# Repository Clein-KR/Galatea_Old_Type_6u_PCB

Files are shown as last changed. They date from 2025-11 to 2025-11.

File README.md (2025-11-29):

# Galatea Old Type 6u PCB

<br />

Geonworks에서 판매했던 Studio Kestra의 Galatea 구형 버전과 호환되는 a87 TKL 유니버셜 PCB입니다.

<br />

**Rendering**

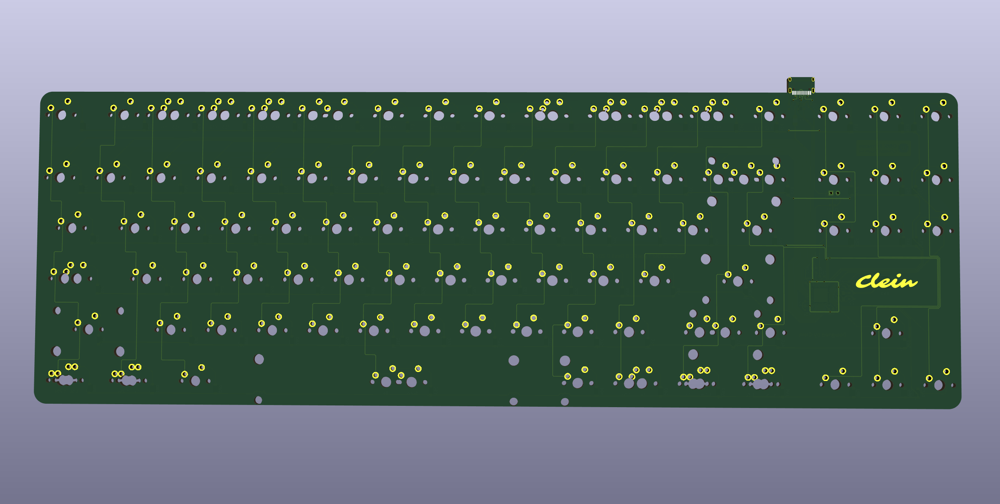
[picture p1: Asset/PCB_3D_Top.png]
PCB Rendering Top View

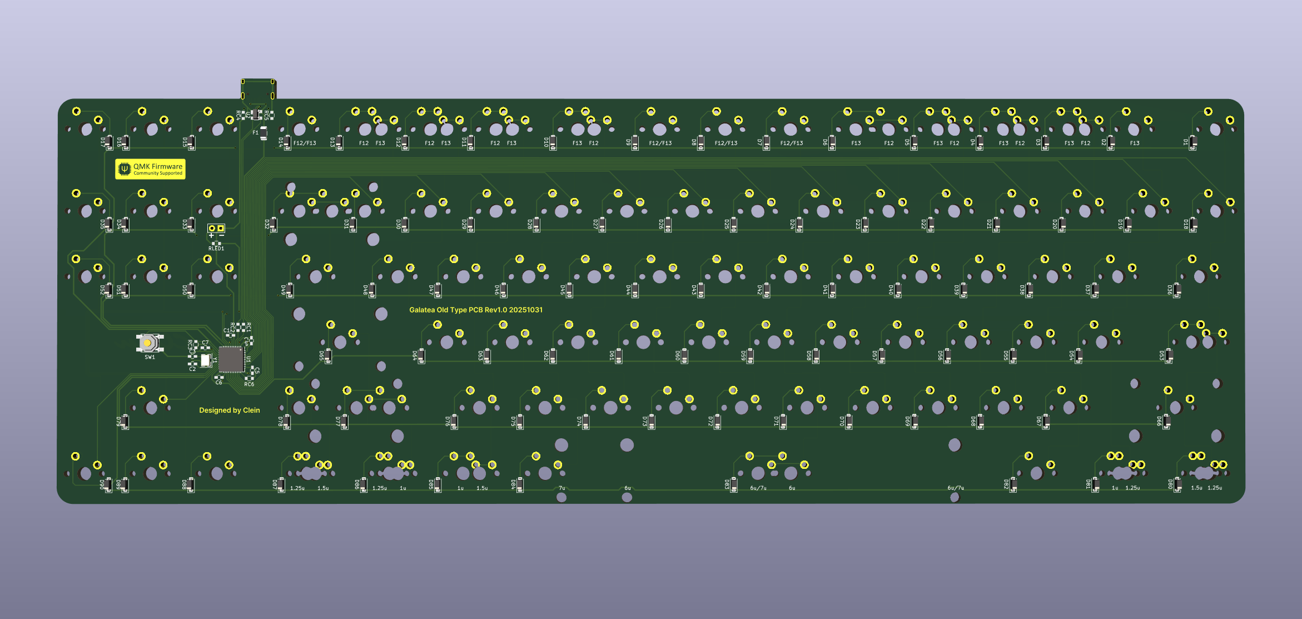
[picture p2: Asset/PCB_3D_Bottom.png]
PCB Rendering Bottom View


<br />

**Prototype**

PCB Prototype Top View
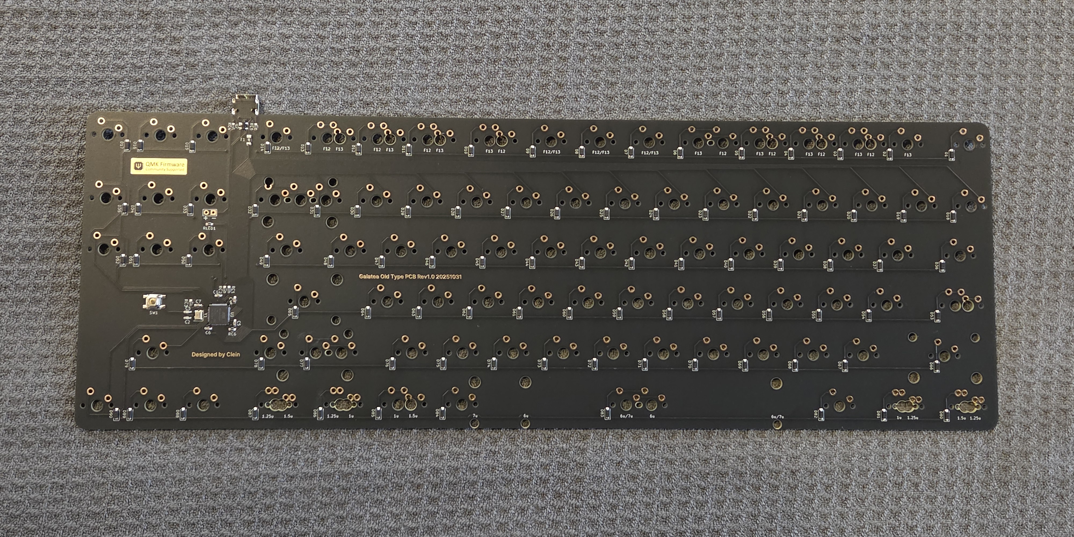
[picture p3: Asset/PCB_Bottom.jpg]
PCB Prototype Bottom View


<br />

**Detail**

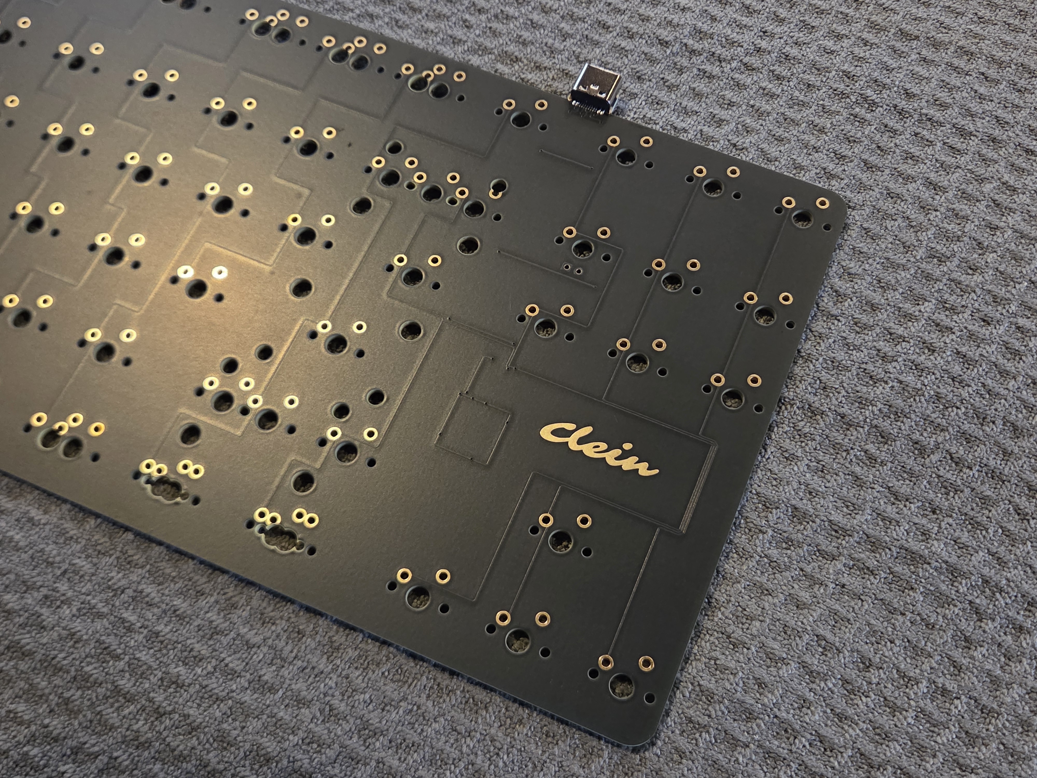
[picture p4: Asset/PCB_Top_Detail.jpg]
PCB Prototype Top Detail View

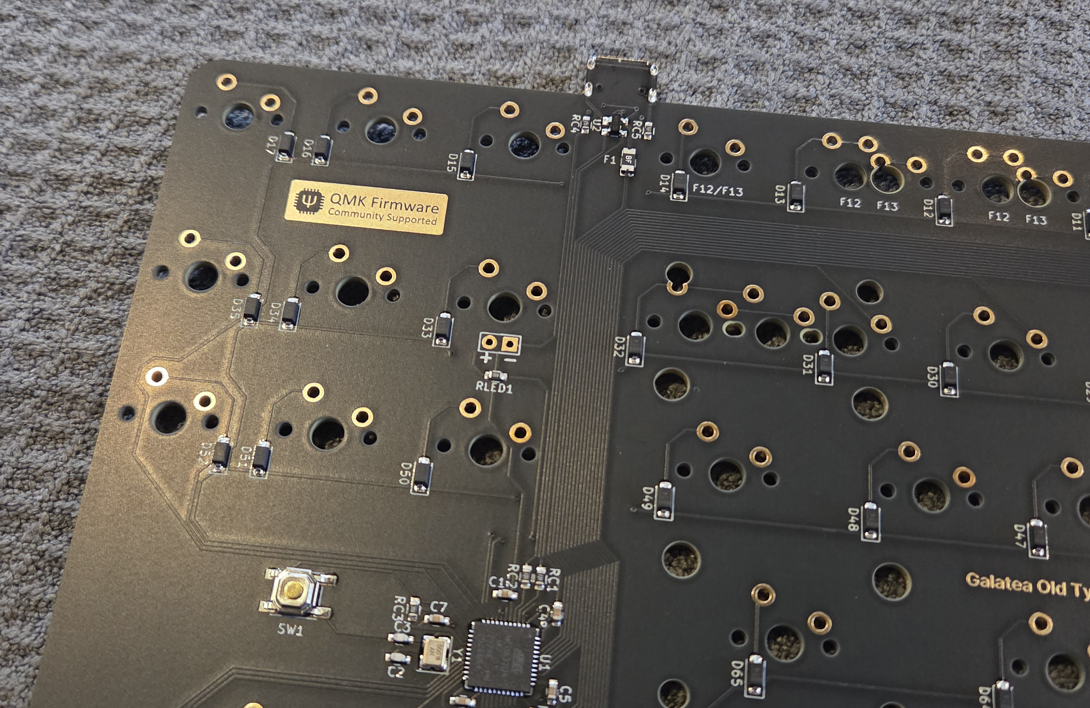
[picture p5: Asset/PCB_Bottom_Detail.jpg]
PCB Prototype Bottom Detail View


<br />

**Compatibility Test**

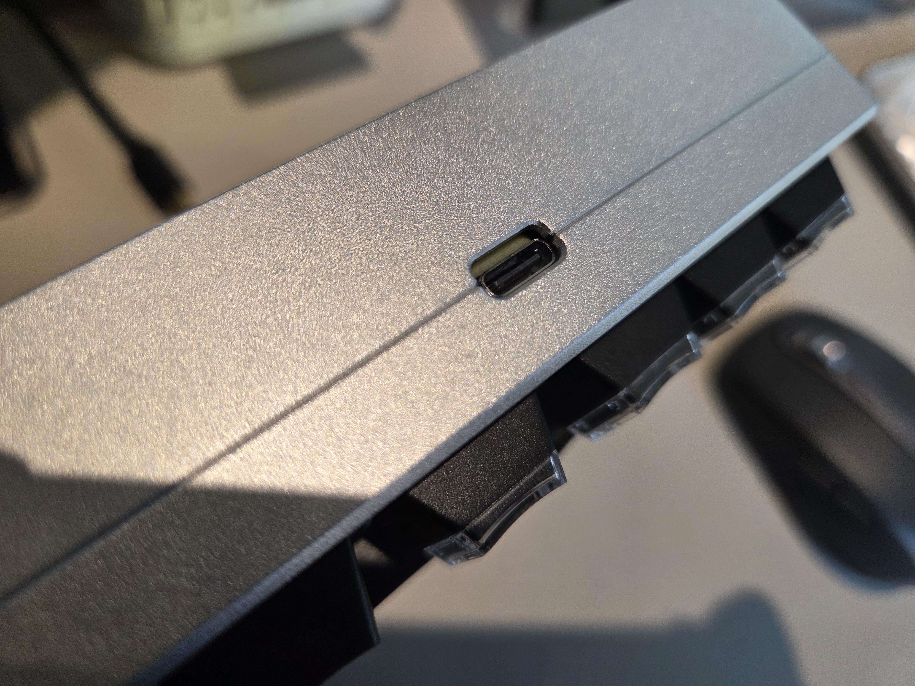
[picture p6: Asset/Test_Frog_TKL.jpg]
Compatibility test of the USB-C port using the Frog TKL


<br />
<br />

## Supported Layout

<br />

해당 PCB는 ISO 배열을 지원하지 않으며, 6.25u 대신 6u 하단열을 지원합니다.

<br />

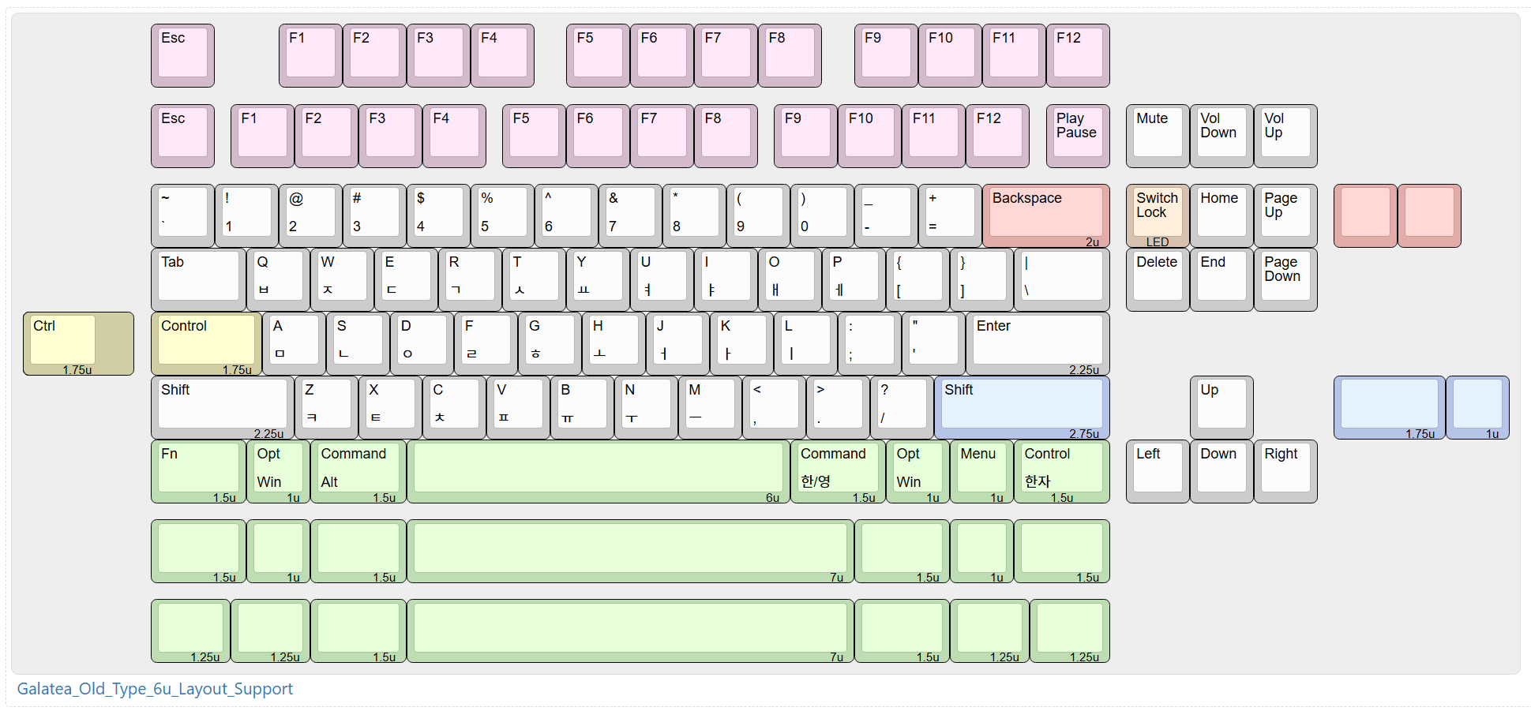
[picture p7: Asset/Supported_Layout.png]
Supported Layout


<br />

또한 기존의 LED 인디케이터를 모두 버리고 Insert 키 위치에 캡스락 LED 인디케이터를 1개 배치하였습니다. 아래는 Vial의 탭댄스 기능을 활용한 인디케이터 테스트 영상입니다.

<br />

[LED_Indicator_with_Tap_Dance.webm](https://github.com/user-attachments/assets/71b8654c-97a3-42a6-80ce-c4df9c4b528a)

<br />
<br />

## Firmware

<br />

펌웨어는 QMK를 기반으로 Via와 Vial을 지원합니다. 펌웨어 소스코드와 Hex 파일은 [여기](/Firmware)에서 다운로드 받으실 수 있습니다.

<br />

```bash
├── Firmware/
│   ├── clein_galatea_old_type_rev_1_0_via.hex
│   └── clein_galatea_old_type_rev_1_0_vial.hex
└── README.md
```

<br />
<br />

## PCB Guide

<br />

PCB와 호환 보강판 제작에 관련된 가이드 도면은 [여기](/Guide)에서 다운로드 받으실 수 있습니다.

<br />

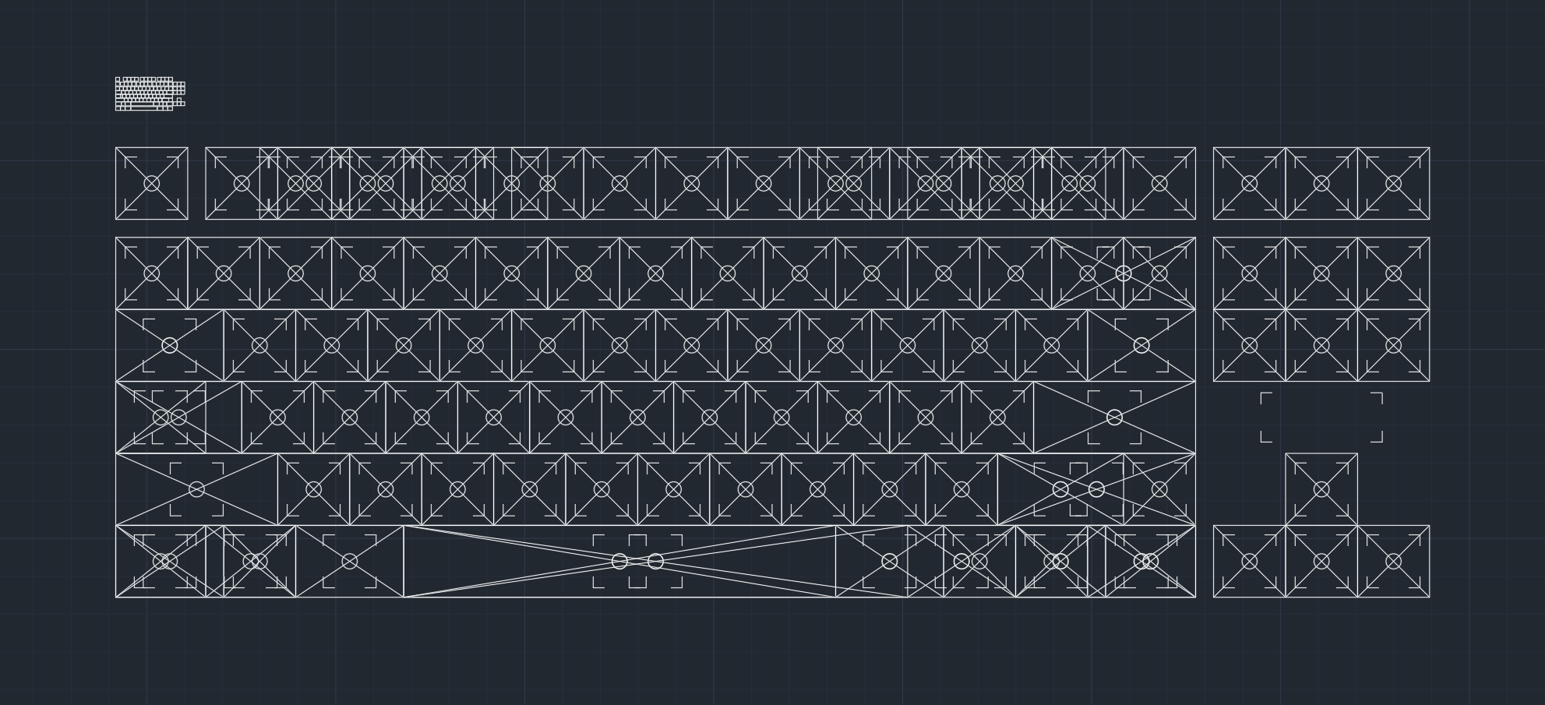
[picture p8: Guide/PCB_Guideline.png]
PCB Guideline

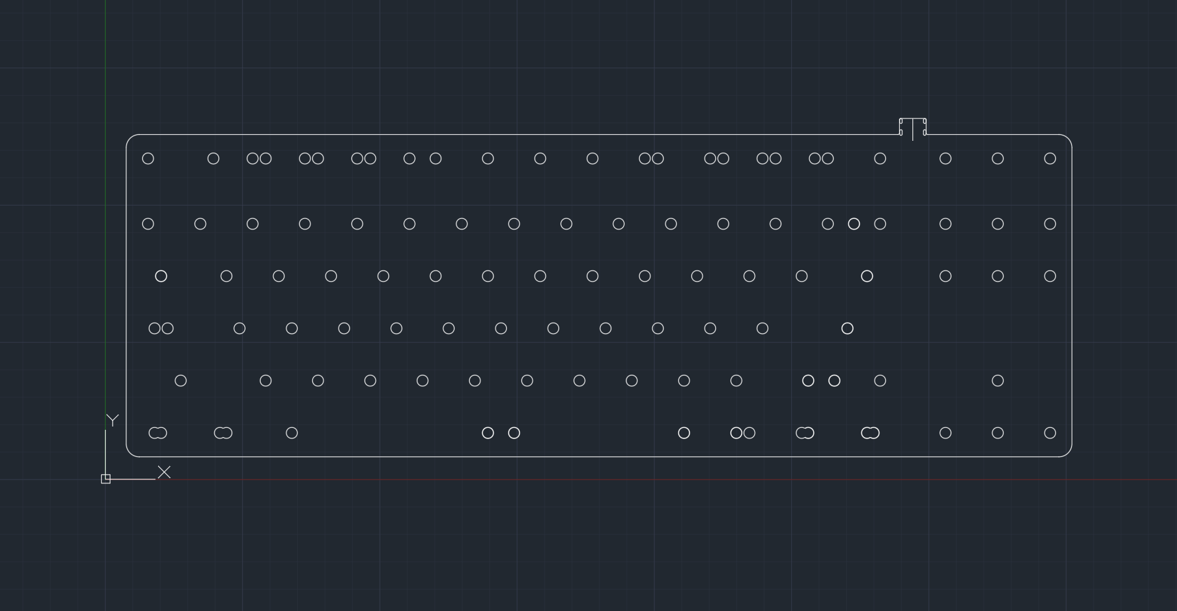
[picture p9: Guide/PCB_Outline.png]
PCB Outline

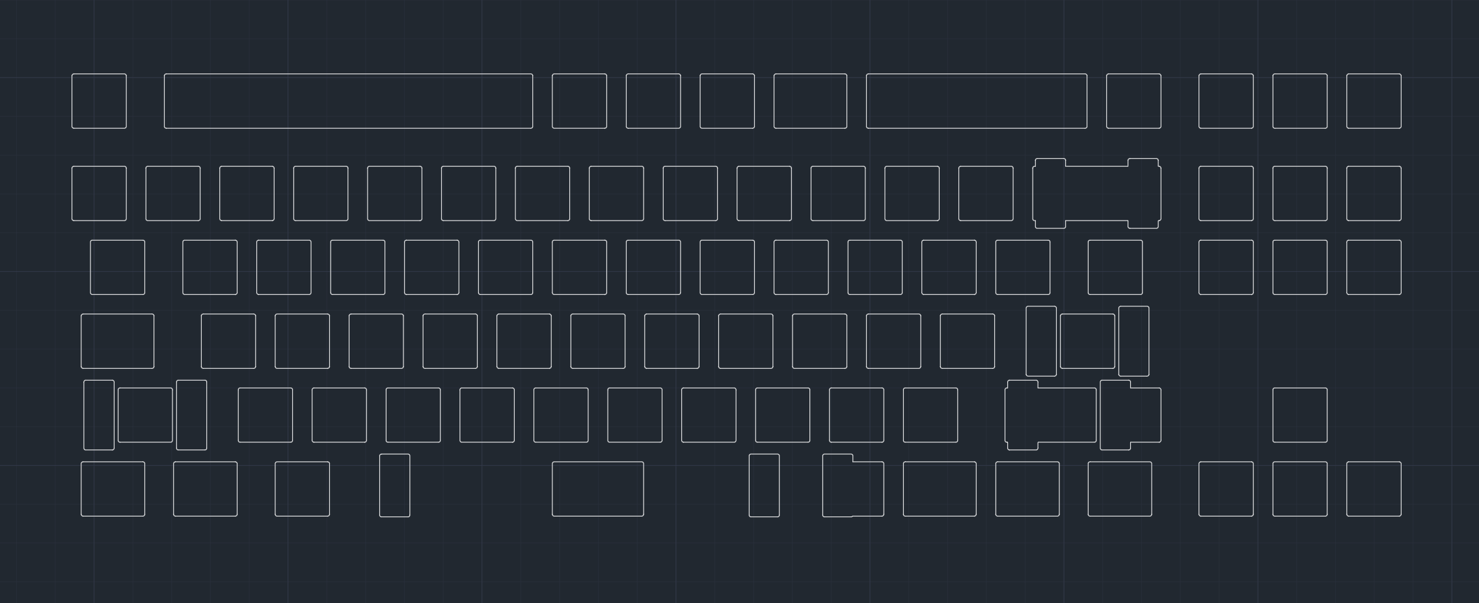
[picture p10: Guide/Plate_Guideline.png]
Plate Guideline


```bash
├── Guide/
│   ├── PCB_Guideline.dxf
│   ├── PCB_Outline.dxf
│   └── Plate_Guideline.dxf
└── README.md
```

<br />
<br />

## How to Order

<br />

해당 PCB의 프로토타입은 [PCBWay](https://pcbway.com)를 통해 제작되었습니다. 프로토타입 제작에 사용되는 파일들은 [여기](/Production)에서 다운로드 받으실 수 있습니다.

<br />

```bash
├── Production/
│   ├── Galatea_Old_Type_6u_PCB_BOM.csv
│   ├── Galatea_Old_Type_6u_PCB_BOM.xlsx
│   ├── Galatea_Old_Type_6u_PCB_Pos_JLCPCB.csv
│   ├── Galatea_Old_Type_6u_PCB_Pos.csv
│   └── Gerber.zip
└── README.md
```

<br />

아래는 적용된 옵션입니다.

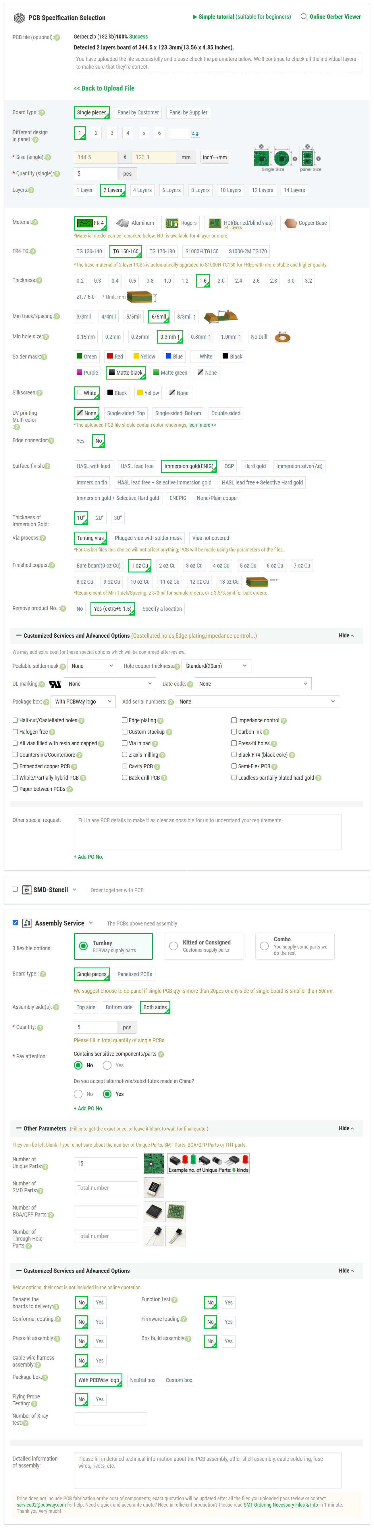
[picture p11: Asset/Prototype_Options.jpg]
Options applied to the PCB prototype


<br />
<br />

## Licence

<br />

해당 프로젝트는 [ai03](https://github.com/ai03-2725) 님의 [KBD8X-MKII-PCB](https://github.com/ai03-2725/KBD8X-MKII-PCB) 프로젝트와 [Joe Scotto](https://github.com/joe-scotto) 님의 [ScottoKeebs](https://github.com/joe-scotto/scottokeebs) 프로젝트를 기반으로 만들어졌습니다. 해당 프로젝트를 활용한 수정, 복제, 배포 등의 활동은 저작자 표시와 함께 비영리적인 목적에 한해서만 가능하며, 라이선스 전문은 [여기](/LICENCE)에서 보실 수 있습니다.

<br />



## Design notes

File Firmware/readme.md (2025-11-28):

# clein/galatea_old_type/rev_1_0

PCB Top 3D View
PCB Bottom 3D View

<br />

PCB Top View
PCB Top View

*A short description of the keyboard/project*

* Keyboard Maintainer: [Clein](https://github.com/Clein-KR)
* Hardware Supported: *The PCBs, controllers supported*
* Hardware Availability: *Links to where you can find this hardware*

Make example for this keyboard (after setting up your build environment):

    make clein/galatea_old_type/rev_1_0:via

Flashing example for this keyboard:

    make clein/galatea_old_type/rev_1_0:via:flash

See the [build environment setup](https://docs.qmk.fm/#/getting_started_build_tools) and the [make instructions](https://docs.qmk.fm/#/getting_started_make_guide) for more information. Brand new to QMK? Start with our [Complete Newbs Guide](https://docs.qmk.fm/#/newbs).

## Bootloader

Enter the bootloader in 3 ways:

* **Bootmagic reset**: Hold down the key at (0,0) in the matrix (usually the top left key or Escape) and plug in the keyboard
* **Physical reset button**: Briefly press the button on the back of the PCB - some may have pads you must short instead
* **Keycode in layout**: Press the key mapped to `QK_BOOT` if it is available

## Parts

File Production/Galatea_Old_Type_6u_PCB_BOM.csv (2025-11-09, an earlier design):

Component | Comment | Description | Part | Designator | Footprint | Pins | Quantity Per PCB | Manufacturer | Mfg Part # | LCSC Part #
1 | 1uF 20% ≥15V X5R/X7R | Capacitor, Ceramic, 0603 | C_Small | C1 | C_0603 | 2 | 1 | HRE | CGA0603X5R105K160JT | C6119849
2 | 22pF 5% ≥15V C0G | Capacitor, Ceramic, 0603 | C_Small | C2, C3 | C_0603 | 2 | 2 | KEMET | C0603C220J4GAC7867 | C561800
3 | 10uF 20% ≥15V X5R/X7R | Capacitor, Ceramic, 0603 | C_Small | C4 | C_0603 | 2 | 1 | HRE | CGA0603X5R106M160JT | C6119814
4 | 0.1uF 20% ≥15V X5R/X7R | Capacitor, Ceramic, 0603 | C_Small | C5, C6, C7 | C_0603 | 2 | 3 | YAGEO | CC0603KRX7R7BB104 | C108079
5 | Generic | Diode, SOD-123 | D_Small | D1, D2, D3, D4, D5, D6, D7, D8, D9, D10, D11, D12, D13, D14, D15, D16, D17, D18, D19, D20, D21, D22, D23, D24, D25, D26, D27, D28, D29, D30, D31, D32, D33, D34, D35, D36, D37, D38, D39, D40, D41, D42, D43, D44, D45, D46, D47, D48, D49, D50, D51, D52, D53, D54, D55, D56, D57, D58, D59, D60, D61, D62, D63, D64, D65, D66, D67, D68, D69, D70, D71, D72, D73, D74, D75, D76, D77, D78, D79, D80, D81, D82, D83, D84, D85, D86, D87, D88, D89, D90 | D_SOD-123 | 2 | 90 | Slkor(SLKORMICRO Elec.) | 1N4148W | C444720
6 | 500mA ≥15V 500mA_Hold 1A_Trip | Polyfuse, 1206 | Polyfuse_Small | F1 | Fuse_SMD1206_Wave | 2 | 1 | BHFUSE | BSMD1206-050-16V | C883124
7 | 22 1% | Resistor, Generic, 0603 | R_Small | RC1, RC2 | R_0603 | 2 | 2 | YAGEO | RC0603FR-0722RL | C107701
8 | 10k 1% | Resistor, Generic, 0603 | R_Small | RC3 | R_0603 | 2 | 1 | YAGEO | RC0603FR-0710KL | C98220
9 | 5.1k 1% | Resistor, Generic, 0603 | R_Small | RC4, RC5 | R_0603 | 2 | 2 | YAGEO | RC0603FR-075K1L | C105580
10 | 1k 1% | Resistor, Generic, 0603 | R_Small | RC6, RLED1 | R_0603 | 2 | 2 | YAGEO | RC0603FR-071KL | C22548
11 | SMT 5.2 x 5.2 x 1.5mm | Push button | SW_Push | SW1 | SKQG-1155865 | 4 | 1 | ALPSALPINE | SKQGABE010 | C115351
12 | ATmega32U4-MU | MCU | ATmega32U4-MU | U1 | QFN-44-1EP_7x7mm_Pitch0.5mm | 45 | 1 | MICROCHIP | ATMEGA32U4-MU | C112161
13 | PRTR5V0U2X | ESD Protection IC | PRTR5V0U2X | U2 | SOT143B | 4 | 1 | Nexperia | PRTR5V0U2X | C12333
14 | HRO-TYPE-C-31-M-12 | USB Type-C Connector | HRO-TYPE-C-31-M-12 | USB1 | HRO-TYPE-C-31-M-12-Assembly | 16 | 1 | Korean Hroparts Elec | TYPE-C-31-M-12 | C165948
15 | 16MHz | Crystal, 3.2 x 2.5mm (3225-4) | Crystal_GND24 | Y1 | Crystal_SMD_3225-4pin_3.2x2.5mm | 4 | 1 | Huiyuan crystal | HY16MSMD3225OB1R30 | C7275098

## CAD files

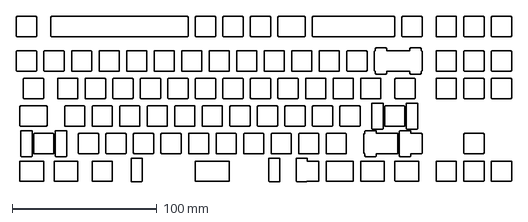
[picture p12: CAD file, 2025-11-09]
Guide/Plate_Guideline.dxf
342.6 x 114.2 mm

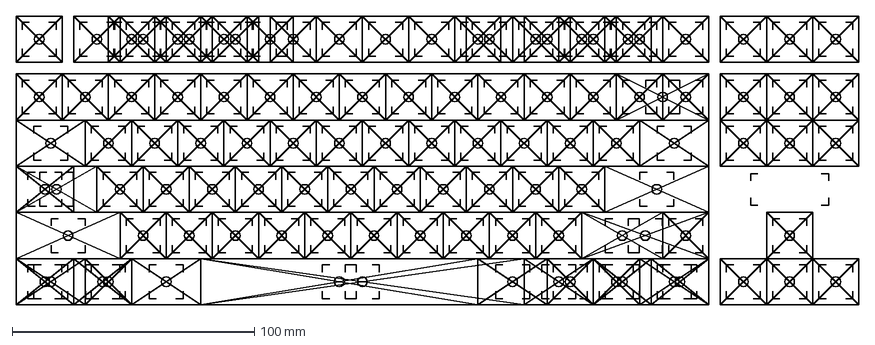
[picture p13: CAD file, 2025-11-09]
Guide/PCB_Guideline.dxf
347.7 x 119.1 mm

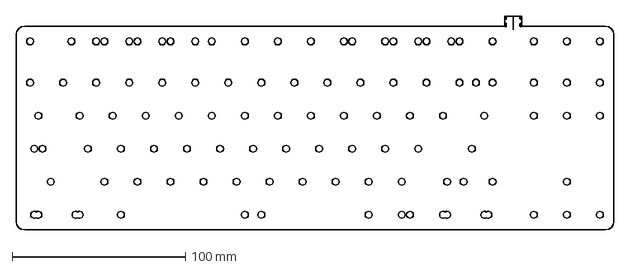
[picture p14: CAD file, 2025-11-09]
Guide/PCB_Outline.dxf
344.5 x 123.3 mm

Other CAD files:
Guide/PCB_Guideline.dwg
Guide/PCB_Outline.dwg
Guide/Plate_Guideline.dwg

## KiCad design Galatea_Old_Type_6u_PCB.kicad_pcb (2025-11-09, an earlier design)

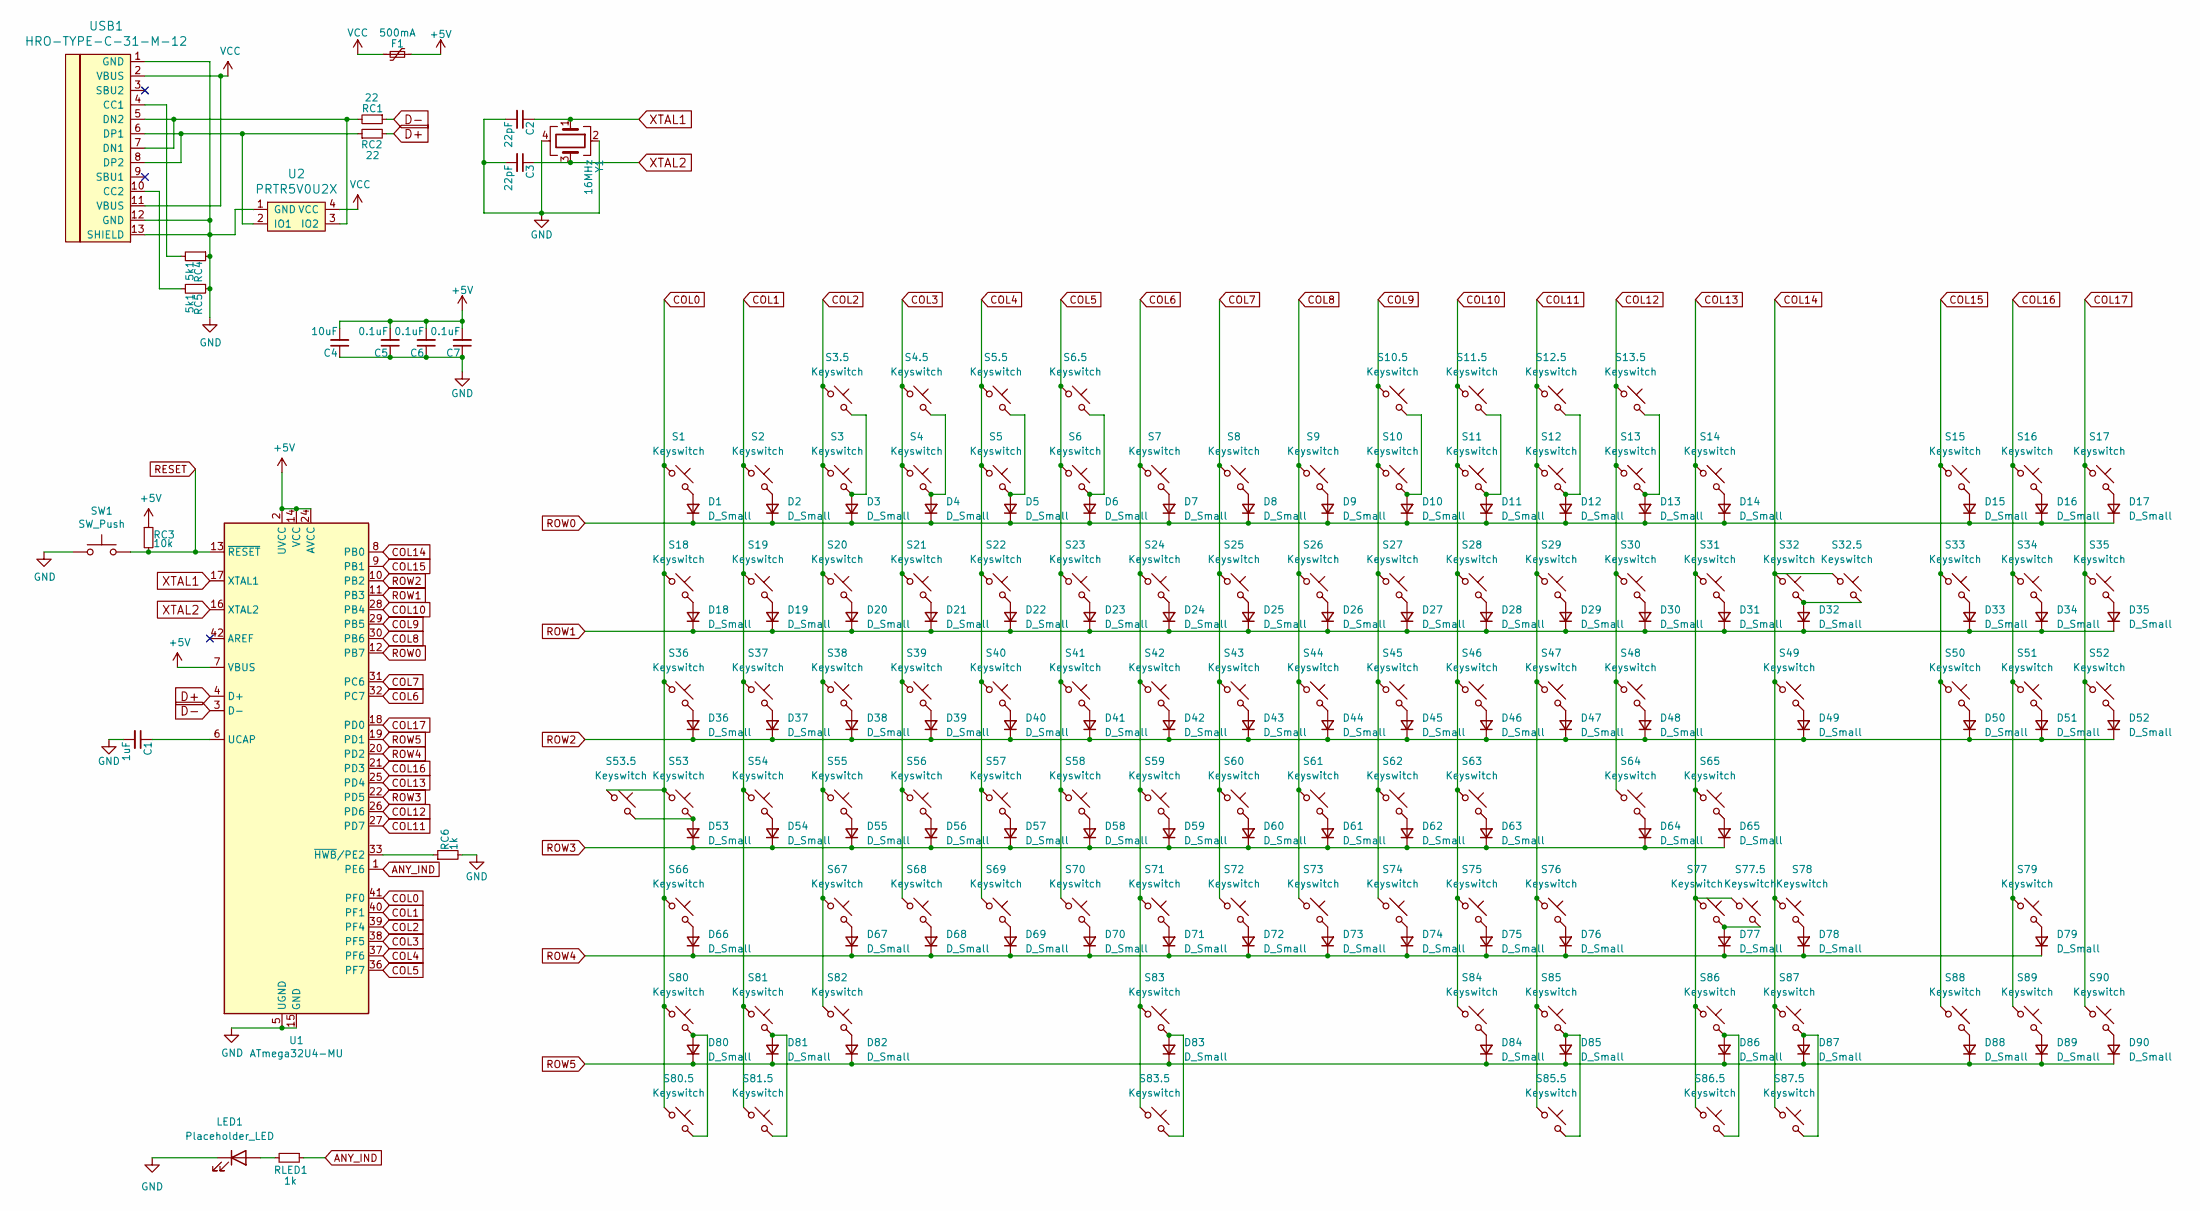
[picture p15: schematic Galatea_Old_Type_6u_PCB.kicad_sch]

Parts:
C1: 1uF; C_0603
C2, C3: 22pF; C_0603
C4: 10uF; C_0603
C5, C6, C7: 0.1uF; C_0603
D1, D2, D3, D4, D5, D6, D7, D8, D9, D10, D11, D12, D13, D14, D15, D16, D17, D18, D19, D20, D21, D22, D23, D24, D25, D26, D27, D28, D29, D30, D31, D32, D33, D34, D35, D36, D37, D38, D39, D40, D41, D42, D43, D44, D45, D46, D47, D48, D49, D50, D51, D52, D53, D54, D55, D56, D57, D58, D59, D60, D61, D62, D63, D64, D65, D66, D67, D68, D69, D70, D71, D72, D73, D74, D75, D76, D77, D78, D79, D80, D81, D82, D83, D84, D85, D86, D87, D88, D89, D90: D_Small; D_SOD-123
F1: 500mA; Fuse_1206_3216Metric
LED1: Placeholder_LED; LED_D3.0mm-Pretty
RC1, RC2: 22; R_0603
RC3: 10k; R_0603
RC4, RC5: 5k1; R_0603
RC6: 1k; R_0603
RLED1: 1k; R_0603
S1, S2, S3, S3.5, S4, S4.5, S5, S5.5, S6, S6.5, S7, S8, S9, S10, S10.5, S11, S11.5, S12, S12.5, S13, S13.5, S14, S15, S16, S17, S18, S19, S20, S21, S22, S23, S24, S25, S26, S27, S28, S29, S30, S31, S32, S32.5, S33, S34, S35, S37, S38, S39, S40, S41, S42, S43, S44, S45, S46, S47, S48, S50, S51, S52, S54, S55, S56, S57, S58, S59, S60, S61, S62, S63, S64, S67, S68, S69, S70, S71, S72, S73, S74, S75, S76, S78, S79, S81, S85.5, S86, S88, S89, S90: Keyswitch; MX_PCB_1.00u
S36, S49, S80, S82, S84, S85, S87: Keyswitch; MX_PCB_1.50u
S53, S77: Keyswitch; MX_PCB_1.75u
S53.5, S80.5, S81.5, S86.5, S87.5: Keyswitch; MX_PCB_1.25u
S65, S66: Keyswitch; MX_PCB_2.25u
S77.5: Keyswitch; MX_PCB_2.75u
S83: Keyswitch; MX_PCB_6.00u
S83.5: Keyswitch; MX_PCB_7.00u
SW1: SW_Push; SKQG-1155865
U1: ATmega32U4-MU; QFN-44-1EP_7x7mm_Pitch0.5mm
U2: PRTR5V0U2X; SOT143B
USB1: HRO-TYPE-C-31-M-12; HRO-TYPE-C-31-M-12-Assembly
Y1: 16MHz; Crystal_SMD_3225-4Pin_3.2x2.5mm

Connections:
+5V: C4.2, C5.2, C6.2, C7.2, F1.1, RC3.1, U1.2 (UVCC), U1.7 (VBUS), U1.14 (VCC), U1.24 (AVCC), U1.34 (VCC), U1.44 (AVCC)
ANY_IND: RLED1.1, U1.1 (PE6)
COL0: S1.1, S18.1, S36.1, S53.1, S53.5.1, S66.1, S80.1, S80.5.1, U1.41 (PF0)
COL1: S2.1, S19.1, S37.1, S54.1, S81.1, S81.5.1, U1.40 (PF1)
COL2: S3.1, S3.5.1, S20.1, S38.1, S55.1, S67.1, S82.1, U1.39 (PF4)
COL3: S4.1, S4.5.1, S21.1, S39.1, S56.1, S68.1, U1.38 (PF5)
COL4: S5.1, S5.5.1, S22.1, S40.1, S57.1, S69.1, U1.37 (PF6)
COL5: S6.1, S6.5.1, S23.1, S41.1, S58.1, S70.1, U1.36 (PF7)
COL6: S7.1, S24.1, S42.1, S59.1, S71.1, S83.1, S83.5.1, U1.32 (PC7)
COL7: S8.1, S25.1, S43.1, S60.1, S72.1, U1.31 (PC6)
COL8: S9.1, S26.1, S44.1, S61.1, S73.1, U1.30 (PB6)
COL9: S10.1, S10.5.1, S27.1, S45.1, S62.1, S74.1, U1.29 (PB5)
COL10: S11.1, S11.5.1, S28.1, S46.1, S63.1, S75.1, S84.1, U1.28 (PB4)
COL11: S12.1, S12.5.1, S29.1, S47.1, S76.1, S85.1, S85.5.1, U1.27 (PD7)
COL12: S13.1, S13.5.1, S30.1, S48.1, S64.1, U1.26 (PD6)
COL13: S14.1, S31.1, S65.1, S77.1, S77.5.1, S86.1, S86.5.1, U1.25 (PD4)
COL14: S32.1, S32.5.1, S49.1, S78.1, S87.1, S87.5.1, U1.8 (PB0)
COL15: S15.1, S33.1, S50.1, S88.1, U1.9 (PB1)
COL16: S16.1, S34.1, S51.1, S79.1, S89.1, U1.21 (PD3)
COL17: S17.1, S35.1, S52.1, S90.1, U1.18 (PD0)
D+: RC2.2, U1.4 (D+)
D-: RC1.1, U1.3 (D-)
GND: C1.2, C2.2, C3.2, C4.1, C5.1, C6.1, C7.1, LED1.1 (K), RC4.1, RC5.1, RC6.2, SW1.1, U1.5 (UGND), U1.15 (GND), U1.23 (GND), U1.35 (GND), U1.43 (GND), U1.45 (GND), U2.1 (GND), USB1.1 (GND), USB1.12 (GND), USB1.13 (SHIELD), Y1.2, Y1.4
unnamed: D1.2 (A), S1.2
unnamed: D2.2 (A), S2.2
unnamed: D3.2 (A), S3.2, S3.5.2
unnamed: D4.2 (A), S4.2, S4.5.2
unnamed: D5.2 (A), S5.2, S5.5.2
unnamed: D6.2 (A), S6.2, S6.5.2
unnamed: D7.2 (A), S7.2
unnamed: D8.2 (A), S8.2
unnamed: D9.2 (A), S9.2
unnamed: D10.2 (A), S10.2, S10.5.2
unnamed: D11.2 (A), S11.2, S11.5.2
unnamed: D12.2 (A), S12.2, S12.5.2
unnamed: D13.2 (A), S13.2, S13.5.2
unnamed: D14.2 (A), S14.2
unnamed: D15.2 (A), S15.2
unnamed: D16.2 (A), S16.2
unnamed: D17.2 (A), S17.2
unnamed: D18.2 (A), S18.2
unnamed: D19.2 (A), S19.2
unnamed: D20.2 (A), S20.2
unnamed: D21.2 (A), S21.2
unnamed: D22.2 (A), S22.2
unnamed: D23.2 (A), S23.2
unnamed: D24.2 (A), S24.2
unnamed: D25.2 (A), S25.2
unnamed: D26.2 (A), S26.2
unnamed: D27.2 (A), S27.2
unnamed: D28.2 (A), S28.2
unnamed: D29.2 (A), S29.2
unnamed: D30.2 (A), S30.2
unnamed: D31.2 (A), S31.2
unnamed: D32.2 (A), S32.2, S32.5.2
unnamed: D33.2 (A), S33.2
unnamed: D34.2 (A), S34.2
unnamed: D35.2 (A), S35.2
unnamed: D36.2 (A), S36.2
unnamed: D37.2 (A), S37.2
unnamed: D38.2 (A), S38.2
unnamed: D39.2 (A), S39.2
unnamed: D40.2 (A), S40.2
unnamed: D41.2 (A), S41.2
unnamed: D42.2 (A), S42.2
unnamed: D43.2 (A), S43.2
unnamed: D44.2 (A), S44.2
unnamed: D45.2 (A), S45.2
unnamed: D46.2 (A), S46.2
unnamed: D47.2 (A), S47.2
unnamed: D48.2 (A), S48.2
unnamed: D49.2 (A), S49.2
unnamed: D50.2 (A), S50.2
unnamed: D51.2 (A), S51.2
unnamed: D52.2 (A), S52.2
unnamed: D53.2 (A), S53.2, S53.5.2
unnamed: D54.2 (A), S54.2
unnamed: D55.2 (A), S55.2
unnamed: D56.2 (A), S56.2
unnamed: D57.2 (A), S57.2
unnamed: D58.2 (A), S58.2
unnamed: D59.2 (A), S59.2
unnamed: D60.2 (A), S60.2
unnamed: D61.2 (A), S61.2
unnamed: D62.2 (A), S62.2
unnamed: D63.2 (A), S63.2
unnamed: D64.2 (A), S64.2
unnamed: D65.2 (A), S65.2
unnamed: D66.2 (A), S66.2
unnamed: D67.2 (A), S67.2
unnamed: D68.2 (A), S68.2
unnamed: D69.2 (A), S69.2
unnamed: D70.2 (A), S70.2
unnamed: D71.2 (A), S71.2
unnamed: D72.2 (A), S72.2
unnamed: D73.2 (A), S73.2
unnamed: D74.2 (A), S74.2
unnamed: D75.2 (A), S75.2
unnamed: D76.2 (A), S76.2
unnamed: D77.2 (A), S77.2, S77.5.2
unnamed: D78.2 (A), S78.2
unnamed: D79.2 (A), S79.2
unnamed: D80.2 (A), S80.2, S80.5.2
unnamed: D81.2 (A), S81.2, S81.5.2
unnamed: D82.2 (A), S82.2
unnamed: D83.2 (A), S83.2, S83.5.2
unnamed: D84.2 (A), S84.2
unnamed: D85.2 (A), S85.2, S85.5.2
unnamed: D86.2 (A), S86.2, S86.5.2
unnamed: D87.2 (A), S87.2, S87.5.2
unnamed: D88.2 (A), S88.2
unnamed: D89.2 (A), S89.2
unnamed: D90.2 (A), S90.2
unnamed: LED1.2 (A), RLED1.2
unnamed: C1.1, U1.6 (UCAP)
unnamed: RC6.1, U1.33 (~HWB/PE2)
unnamed: RC2.1, U2.2 (IO1), USB1.6 (DP1), USB1.8 (DP2)
unnamed: RC1.2, U2.3 (IO2), USB1.5 (DN2), USB1.7 (DN1)
unnamed: RC4.2, USB1.4 (CC1)
unnamed: RC5.2, USB1.10 (CC2)
RESET: RC3.2, SW1.2, U1.13 (~RESET)
ROW0: D1.1 (K), D2.1 (K), D3.1 (K), D4.1 (K), D5.1 (K), D6.1 (K), D7.1 (K), D8.1 (K), D9.1 (K), D10.1 (K), D11.1 (K), D12.1 (K), D13.1 (K), D14.1 (K), D15.1 (K), D16.1 (K), D17.1 (K), U1.12 (PB7)
ROW1: D18.1 (K), D19.1 (K), D20.1 (K), D21.1 (K), D22.1 (K), D23.1 (K), D24.1 (K), D25.1 (K), D26.1 (K), D27.1 (K), D28.1 (K), D29.1 (K), D30.1 (K), D31.1 (K), D32.1 (K), D33.1 (K), D34.1 (K), D35.1 (K), U1.11 (PB3)
ROW2: D36.1 (K), D37.1 (K), D38.1 (K), D39.1 (K), D40.1 (K), D41.1 (K), D42.1 (K), D43.1 (K), D44.1 (K), D45.1 (K), D46.1 (K), D47.1 (K), D48.1 (K), D49.1 (K), D50.1 (K), D51.1 (K), D52.1 (K), U1.10 (PB2)
ROW3: D53.1 (K), D54.1 (K), D55.1 (K), D56.1 (K), D57.1 (K), D58.1 (K), D59.1 (K), D60.1 (K), D61.1 (K), D62.1 (K), D63.1 (K), D64.1 (K), D65.1 (K), U1.22 (PD5)
ROW4: D66.1 (K), D67.1 (K), D68.1 (K), D69.1 (K), D70.1 (K), D71.1 (K), D72.1 (K), D73.1 (K), D74.1 (K), D75.1 (K), D76.1 (K), D77.1 (K), D78.1 (K), D79.1 (K), U1.20 (PD2)
ROW5: D80.1 (K), D81.1 (K), D82.1 (K), D83.1 (K), D84.1 (K), D85.1 (K), D86.1 (K), D87.1 (K), D88.1 (K), D89.1 (K), D90.1 (K), U1.19 (PD1)
VCC: F1.2, U2.4 (VCC), USB1.2 (VBUS), USB1.11 (VBUS)
XTAL1: C2.1, U1.17 (XTAL1), Y1.1
XTAL2: C3.1, U1.16 (XTAL2), Y1.3

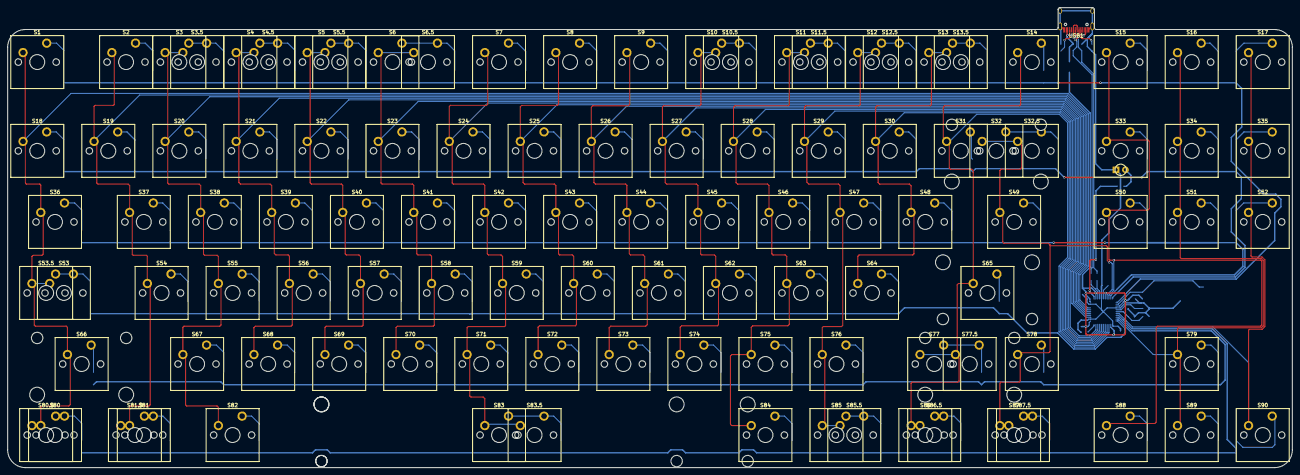
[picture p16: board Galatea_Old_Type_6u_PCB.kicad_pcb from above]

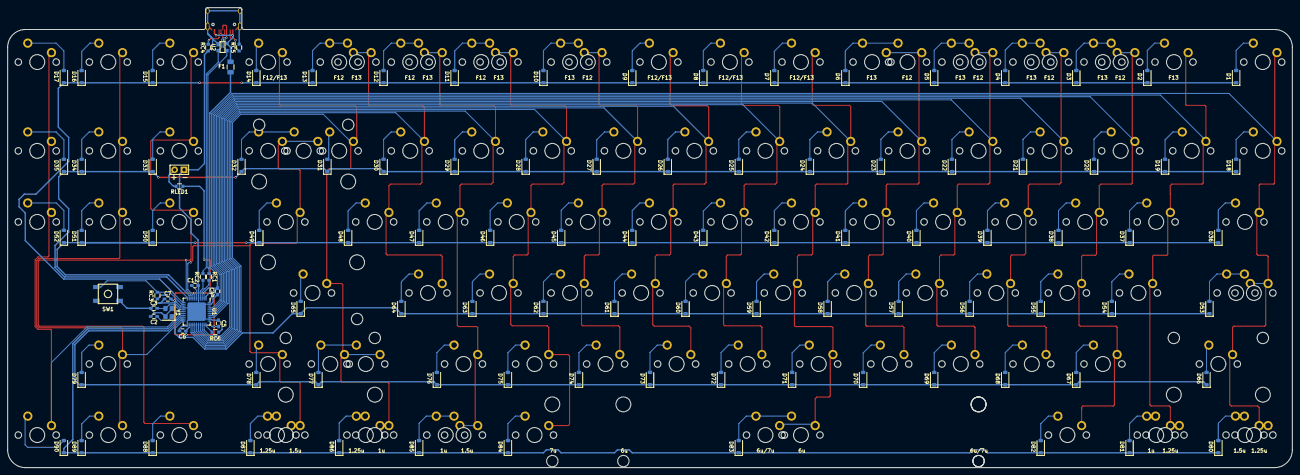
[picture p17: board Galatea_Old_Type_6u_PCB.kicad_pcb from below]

Board: 2 copper layers, 344.5 x 123.3 mm, 218 parts (109 on the bottom side), 130 nets.

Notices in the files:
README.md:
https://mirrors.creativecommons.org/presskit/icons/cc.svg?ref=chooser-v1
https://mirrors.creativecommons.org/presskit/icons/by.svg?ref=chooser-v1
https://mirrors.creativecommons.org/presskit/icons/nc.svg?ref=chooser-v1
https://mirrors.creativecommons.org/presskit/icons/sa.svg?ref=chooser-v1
